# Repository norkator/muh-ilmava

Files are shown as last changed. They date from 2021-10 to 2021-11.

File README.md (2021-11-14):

# MUH Ilmava

MUH Ilmava Arduino temperature and humidity sensing hacks, 
which idea is to learn from gathering temperature and humidity data how this unit works and what can data analysis do.
Another purpose is to see how much this one heat transfer cell can gather heat and how much is dumped to `R4` channel.

See plotting for better image what you can plot with just few DHT22 sensors in each channel.
  
I am currently just waiting due need to gather a lot of data so this repository code could possibly get some more 
"features" based on findings, learning curve and analysis of gathered material.

Ilmava
============
MUH Ilmava is a house ventilation system and this specific unit is very old one from ~1989.

Sensor placing
============
Temperature|humidity sensors labeled as R1, R2, R3, R4 are placed in following way.  
`R1` - Incoming outside air.  
`R2` - Outgoing air to rooms.  
`R3` - Returning air from rooms.  
`R4` - Waste air outside house.

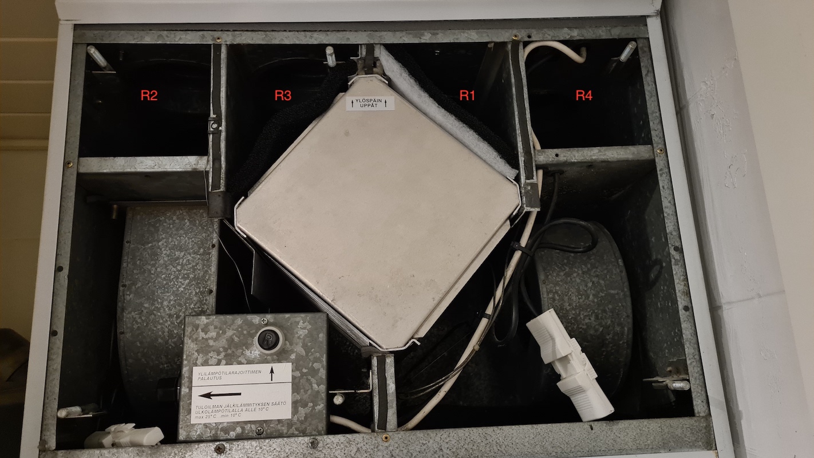
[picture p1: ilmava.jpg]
ilmava_sensor_placing


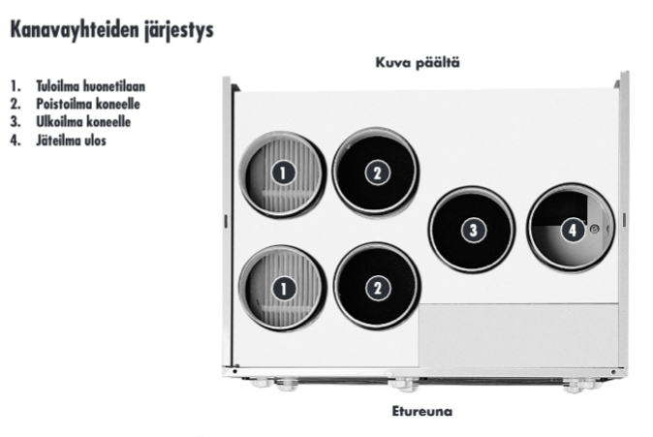
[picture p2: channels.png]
air_channels


Schematic
============
* I used regular 12v power supply to supply main input power. 
* To avoid frying your Arduino regulator, you should use external power regulator like lm2596
to provide 5v out for attached sensors.
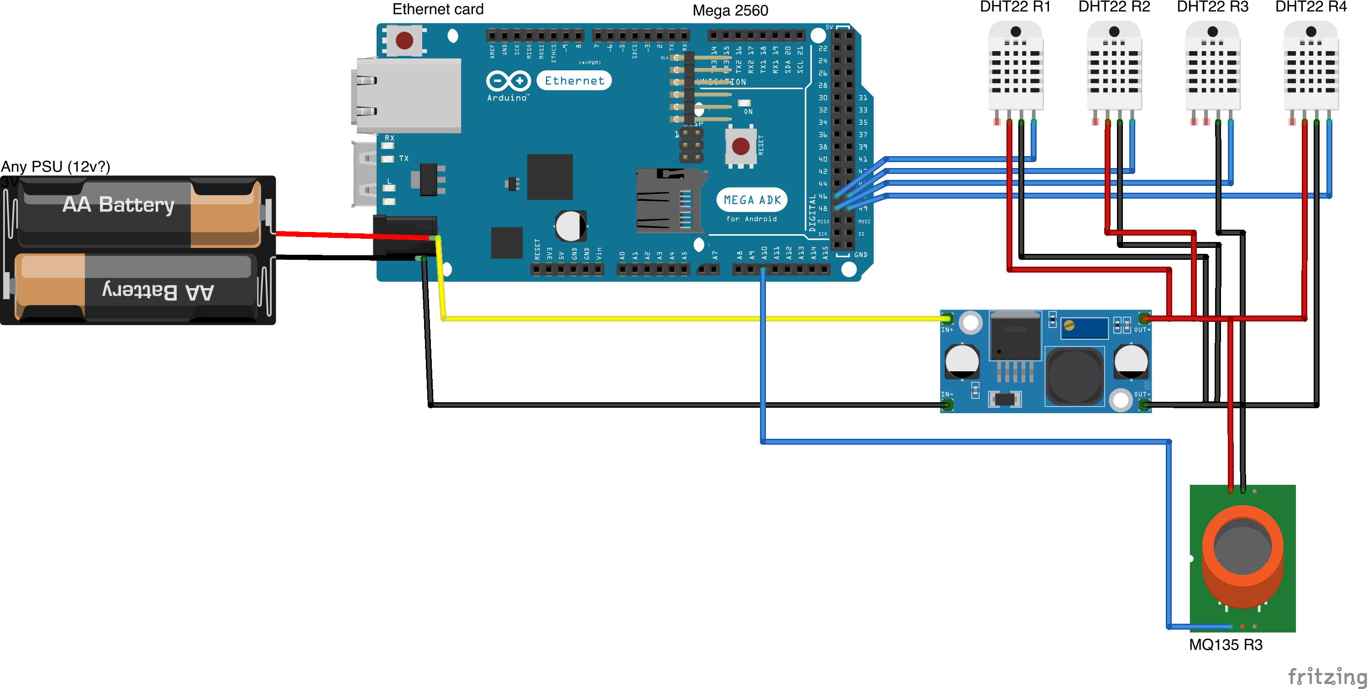
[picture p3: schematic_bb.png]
schematic_bb
 

Backend
============
Is located at `/server` folder. It's a simple express backend which takes data and stores it into PostgreSQL database. 

#### Running backend
Check db schema status
```
yarn migrate:status
```
Migrate to latest schema if needed
```
yarn migrate
```
Run backend. You should run it with something else like `PM2` process manager.
```
node ilmava.js
```

Plotting
============
For plotting data I used `Superset`. I run it locally with Docker as their documentation instructs.
Get started with Superset [here](https://superset.apache.org/).

Why Superset?
* It doesn't no longer make sense to create custom plotting front end since Superset just gives you 
so many possibilities.

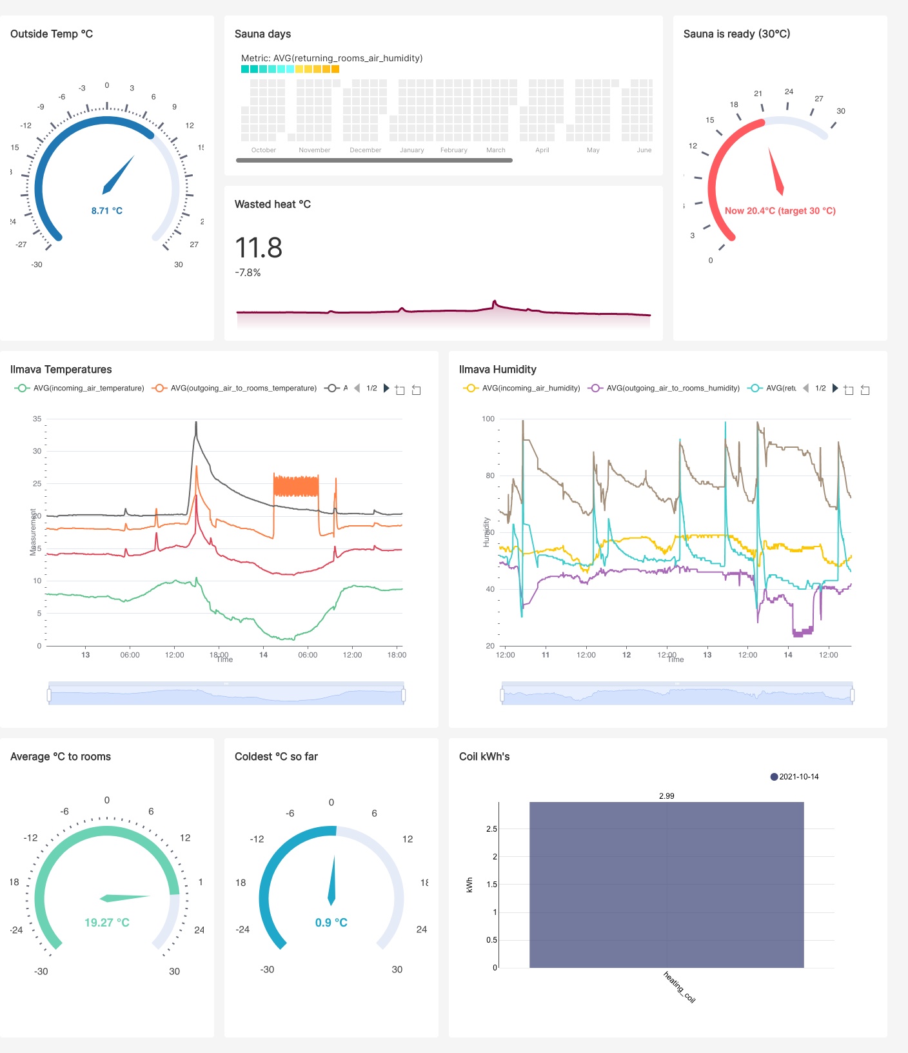
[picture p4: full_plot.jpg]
plotting
 

Queries
============

Need
----
is to find out how much heating coil has used kWh's of energy.  
`500` = coil watt rating.
```postgresql
select
    started::date as date,
    500 * (duration_minutes / 60) / 1000 as used_kwh
from (
         select min("createdAt")                       as started,
                max("createdAt")                       as ended,
                EXTRACT(EPOCH FROM (max("createdAt") - min("createdAt"))::INTERVAL) /
                60                                     as "duration_minutes",
                avg(outgoing_air_to_rooms_temperature) as "avg_temp"
         from measurements
         where outgoing_air_to_rooms_temperature > 21
           and outgoing_air_to_rooms_humidity < 27
         group by "createdAt"::date
     ) as m
```

Coil is not on the whole time so maybe right value is about 70% of it:

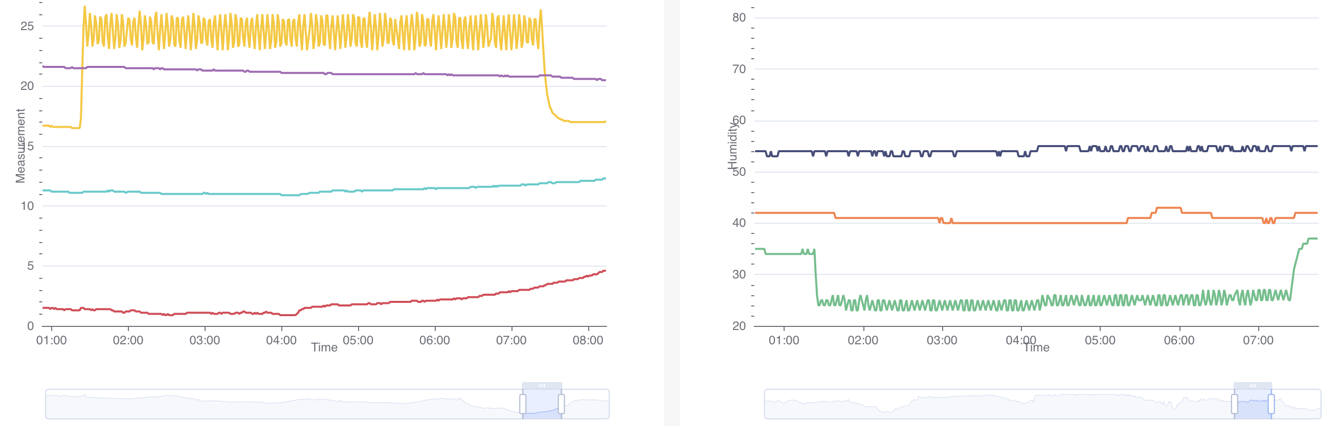
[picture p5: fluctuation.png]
fluctuation


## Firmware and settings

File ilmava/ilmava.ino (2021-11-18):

/**
 * MUH Ilmava Temperature measuring and sender device
 * Arduino: Mega2560
 * Temperature sensors: 4 x DHT22
 * + Ethernet Card (NOTE: 50, 51, 52, 53 are somehow used by wiznet)
 *  
 *  Oled screen support
 *  To enable following screen support you need to install libs: "Adafruit BusIO", "Adafruit-GFX-Library" and "Adafruit_SSD1306"
 *  Display pins:
 *     SDA -> A4 (i2c)
 *     SCL -> A5 (i2c)
 *     GND -> Ground
 *     VDD -> 5v (Screen pin labeled as VCC or VDD)
 *
 */
// --------------------------------------------------------------------------------
// ## Libraries ##
#include <ArduinoJson.h>
#include <SPI.h>
#include <Dhcp.h>
#include <Dns.h>
#include <Ethernet.h>
#include <EthernetClient.h>
#include <EthernetServer.h>
#include <EthernetUdp.h>
#include <ArduinoJson.h>
#include <dht.h>
#include <TaskScheduler.h>
#include <MQ135.h>

// --------------------------------------------------------------------------------
// ## Pins config ##
#define DHT22_1_PIN 46
#define DHT22_2_PIN 47
#define DHT22_3_PIN 48
#define DHT22_4_PIN 49
// const int MQ135_1_PIN = A8;
const int MQ135_2_PIN = A9;
const int MQ135_3_PIN = A10;
// const int MQ135_4_PIN = A11;

// --------------------------------------------------------------------------------
// ## Variables ##
dht DHT;
MQ135 mq2 = MQ135(MQ135_2_PIN, 80.00);
MQ135 mq3 = MQ135(MQ135_3_PIN, 56.39);

double incomingAirTemp = 0.0;
int incomingAirHumidity = 0;
double incomingAirDioxide = 0.0;
double incomingAirMonoxide = 0.0;

double outgoingAirToRoomsTemp = 0.0;
int outgoingAirToRoomsHumidity = 0;
double outgoingAirToRoomsDioxide = 0.0;
double outgoingAirToRoomsMonoxide = 0.0;

double returningRoomsAirTemp = 0.0;
int returningRoomsAirHumidity = 0;
double returningRoomsAirDioxide = 0.0;
double returningRoomsAirMonoxide = 0.0;

double wasteAirOutTemp = 0.0;
int wasteAirOutHumidity = 0;
double wasteAirOutDioxide = 0.0;
double wasteAirOutMonoxide = 0.0;

long timePreviousMeassure = 0;

// --------------------------------------------------------------------------------
// ## "Calibration" ##
static double INCOMING_AIR_T_CORRECTION = 1.2;
static double OUTGOING_AIR_TO_ROOMS_T_CORRECTION = 0.9;
static double RETURNING_ROOMS_AIR_T_CORRECTION = -0.6;
static double WASTE_AIR_OUT_T_CORRECTION = 0.0;

// --------------------------------------------------------------------------------
// ## Ethernet config ##
EthernetClient client;
byte mac[] = { 0x2E, 0xA8, 0xA9, 0xB5, 0xDA, 0xF6 };
const char* server  = "192.168.2.35"; // Where stuff is sent at
const char* api     = "/device/v1/measurements";
const int port      = 8080;
const unsigned long HTTP_TIMEOUT = 10000;
const size_t MAX_CONTENT_SIZE = 1024; // Must be incremented if http response comes out as null

// --------------------------------------------------------------------------------
// ## Task scheduler config ##
Scheduler runner;
void dhtRead();
void dioxideRead();
void monoxideRead();
void httpPostRequest();
Task t1(11 * 1000, TASK_FOREVER, &dhtRead);
Task t2(11 * 1000, TASK_FOREVER, &dioxideRead);
Task t3(11 * 1000, TASK_FOREVER, &monoxideRead);
Task t4(30 * 1000, TASK_FOREVER, &httpPostRequest);    int httpSkip = 0; // Skip some

// --------------------------------------------------------------------------------

// SETUP
void setup() {
  Serial.begin(9600);

  // init ethernet
  if (!Ethernet.begin(mac)) { // DHCP
    Serial.println("Ethernet configure failed!");
  } else {
    Serial.println("Ethernet init ok.");
    Serial.println(Ethernet.localIP());
  }

  // check rzeros for mq sensors 
  float rzero_2 = mq2.getRZero();
  float rzero_3 = mq3.getRZero();
  Serial.println("MQ135 Rzeros");
  Serial.println(rzero_2);
  Serial.println(rzero_3);

  // init task scheduler
  runner.init();
  runner.addTask(t1); // dht
  runner.addTask(t2); // dioxide
  runner.addTask(t3); // monoxide
  runner.addTask(t4); // http call
  t1.enable();
  t2.enable();
  t3.enable();
  t4.enable();

  delay(5 * 1000);
}

// --------------------------------------------------------------------------------

// LOOP
void loop() {
  runner.execute(); // Runner is responsible for all tasks
}

// --------------------------------------------------------------------------------------------------------------------------
// -------------------------------------A L L - S E N S O R - R E A D I N G - T A S K S -------------------------------------
// --------------------------------------------------------------------------------------------------------------------------

// Read DHT temperature and humidity
void dhtRead() {  
  int chk = DHT.read22(DHT22_1_PIN);  
  incomingAirTemp = DHT.temperature + INCOMING_AIR_T_CORRECTION;
  incomingAirHumidity = DHT.humidity;
  Serial.print("Incoming Air temp: ");
  Serial.print(incomingAirTemp);
  Serial.println("°C");
  Serial.print("Incoming Air humidity: ");
  Serial.print(incomingAirHumidity);
  Serial.println("rH");

  chk = DHT.read22(DHT22_2_PIN);  
  outgoingAirToRoomsTemp = DHT.temperature + OUTGOING_AIR_TO_ROOMS_T_CORRECTION;
  outgoingAirToRoomsHumidity = DHT.humidity;
  Serial.print("Outgoing Air To Rooms temp: ");
  Serial.print(outgoingAirToRoomsTemp);
  Serial.println("°C");
  Serial.print("Outgoing Air To Rooms humidity: ");
  Serial.print(outgoingAirToRoomsHumidity);
  Serial.println("rH");

  chk = DHT.read22(DHT22_3_PIN);  
  returningRoomsAirTemp = DHT.temperature + RETURNING_ROOMS_AIR_T_CORRECTION;
  returningRoomsAirHumidity = DHT.humidity;
  Serial.print("Returning Rooms Air temp: ");
  Serial.print(returningRoomsAirTemp);
  Serial.println("°C");
  Serial.print("Returning Rooms Air humidity: ");
  Serial.print(returningRoomsAirHumidity);
  Serial.println("rH");

  chk = DHT.read22(DHT22_4_PIN);  
  wasteAirOutTemp = DHT.temperature + WASTE_AIR_OUT_T_CORRECTION;
  wasteAirOutHumidity = DHT.humidity;
  Serial.print("Waste Air Out temp: ");
  Serial.print(wasteAirOutTemp);
  Serial.println("°C");
  Serial.print("Waste Air Out humidity: ");
  Serial.print(wasteAirOutHumidity);
  Serial.println("rH");

  Serial.println("------------------------------------");
}

// Read carbon dioxide sensors (MQ-135)
void dioxideRead() {
  // outgoingAirToRoomsDioxide = analogRead(MQ135_2_PIN);
  outgoingAirToRoomsDioxide = mq2.getCorrectedPPM(outgoingAirToRoomsTemp, returningRoomsAirHumidity);
  Serial.print("Outgoing Air To Rooms carbon dioxide: ");
  Serial.print(outgoingAirToRoomsDioxide);
  Serial.println(" PPM");
  
  // returningRoomsAirDioxide = analogRead(MQ135_3_PIN);
  returningRoomsAirDioxide = mq3.getCorrectedPPM(returningRoomsAirTemp, returningRoomsAirHumidity);
  Serial.print("Returning Rooms Air carbon dioxide: ");
  Serial.print(returningRoomsAirDioxide);
  Serial.println(" PPM");

  Serial.println("------------------------------------");
}

// Read carbon monoxide sensors (MQ-9)
void monoxideRead() {
  // currently don't have any
}


// --------------------------------------------------------------------------------------------------------------------------
// ----------------------------------------- H T T P - A P I - C A L L - T A S K --------------------------------------------
// --------------------------------------------------------------------------------------------------------------------------

// Http post operation
void httpPostRequest() {
    if (httpSkip == 0) {
      Serial.print("Http callback");
      if (connect(server)) {
        Serial.print(server); Serial.print(":"); Serial.print(port); Serial.println(api);
        if (sendRequest(server, api) && skipResponseHeaders()) {
          char response[MAX_CONTENT_SIZE];
          readReponseContent(response, sizeof(response));
          parseResponseData(response);
        }
        disconnect();
      }
    }
    httpSkip = httpSkip +1;
    if (httpSkip == 2) {
      httpSkip = 0;
    };
}

// Open connection to the HTTP server
bool connect(const char* hostName) {
  Serial.println("");
  Serial.print("Connecting to: ");
  Serial.print(hostName); Serial.print(":"); Serial.print(port);
  Serial.println("");
  bool ok = client.connect(hostName, port);
  Serial.println(ok ? "Connected" : "Connection Failed!");
  Serial.println(client.remoteIP());
  return ok;
}

// Send the HTTP POST request to the server, same time GET needed response data
bool sendRequest(const char* host, const char* api) {

  // Construct json parameter object
  StaticJsonBuffer<1200> jsonBuffer; // This seems not to affect anywhere
  StaticJsonBuffer<500> jsonBuffer2; // Increment more based on Object count
  JsonObject& root = jsonBuffer.createObject();
  // root["firmwareBuild"] = firmware_build;
  JsonArray& data = root.createNestedArray("data");

  JsonObject& incomingAirObj = jsonBuffer2.createObject();
  incomingAirObj["name"] = "incoming_air";
  incomingAirObj["temp"] = incomingAirTemp;
  incomingAirObj["hum"] = incomingAirHumidity;
  // incomingAirObj["dioxide"] = incomingAirDioxide;
  // incomingAirObj["monoxide"] = incomingAirMonoxide;

  JsonObject& outgoingAirToRoomsObj = jsonBuffer2.createObject();
  outgoingAirToRoomsObj["name"] = "outgoing_air_to_rooms";
  outgoingAirToRoomsObj["temp"] = outgoingAirToRoomsTemp;
  outgoingAirToRoomsObj["hum"] = outgoingAirToRoomsHumidity;
  outgoingAirToRoomsObj["dioxide"] = outgoingAirToRoomsDioxide;
  // outgoingAirToRoomsObj["monoxide"] = outgoingAirToRoomsMonoxide;

  JsonObject& returningRoomsAirObj = jsonBuffer2.createObject();
  returningRoomsAirObj["name"] = "returning_rooms_air";
  returningRoomsAirObj["temp"] = returningRoomsAirTemp;
  returningRoomsAirObj["hum"] = returningRoomsAirHumidity;
  returningRoomsAirObj["dioxide"] = returningRoomsAirDioxide;
  // returningRoomsAirObj["monoxide"] = returningRoomsAirMonoxide;
  

  JsonObject& wasteAirOutObj = jsonBuffer2.createObject();
  wasteAirOutObj["name"] = "waste_air_out";
  wasteAirOutObj["temp"] = wasteAirOutTemp;
  wasteAirOutObj["hum"] = wasteAirOutHumidity;
  wasteAirOutObj["dioxide"] = wasteAirOutDioxide;
  // wasteAirOutObj["monoxide"] = wasteAirOutMonoxide;

  // Append to data array
  data.add(incomingAirObj);
  data.add(outgoingAirToRoomsObj);
  data.add(returningRoomsAirObj);
  data.add(wasteAirOutObj);

  String postData = "";
  root.printTo(postData);
  Serial.println(postData);

  // Http post
  Serial.print("POST ");
  Serial.println(api);
  client.print("POST ");
  client.print(api);
  client.println(" HTTP/1.1");
  client.print("Host: ");
  client.println(server);
  //client.println("Content-Type: application/x-www-form-urlencoded");
  client.println("Content-Type: application/json");
  client.println("User-Agent: Arduino/1.0");
  client.println("Connection: close");
  client.print("Content-Length: ");
  client.println(postData.length());
  client.println();
  client.print(postData);
  client.println();

  return true;
}

// --------------------------------------------------------------------------------

// Skip HTTP headers so that we are at the beginning of the response's body
bool skipResponseHeaders() {
  // HTTP headers end with an empty line
  char endOfHeaders[] = "\r\n\r\n";
  client.setTimeout(HTTP_TIMEOUT);
  bool ok = client.find(endOfHeaders);
  if (!ok) {
    Serial.println("No response or invalid response!");
  }
  return ok;
}

// --------------------------------------------------------------------------------

// Read the body of the response from the HTTP server
void readReponseContent(char* content, size_t maxSize) {
  size_t length = client.readBytes(content, maxSize);
  content[length] = 0;
}

// --------------------------------------------------------------------------------

// Parse response data (commands) and apply them
void parseResponseData(char* content) {
  StaticJsonBuffer<MAX_CONTENT_SIZE> jsonBuffer; // Increment MAX_CONTENT_SIZE constant variable if repsonse is null
  JsonObject& root = jsonBuffer.parseObject(content);

  Serial.println("---------- HTTP RESPONSE ----------");
  String responseData = "";
  Serial.println(responseData);
  Serial.println("-----------------------------------");

  if (!root.success()) {
    Serial.println("JSON parsing failed!");
    return;
  }

}

// --------------------------------------------------------------------------------

// Close the connection with the HTTP server
void disconnect() {
  Serial.println("Disconnect");
  client.stop();
}

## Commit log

2021-10-04 Code to read temps
    Some skeleton celsius converter which most likely does not work
    [ilmava.ino]
2021-10-04 Add sensor placing plan
2021-10-04 Fixed code to cover all requirements
    [ilmava.ino]
2021-10-09 Take up previous millis
2021-10-10 Refactored Arduino side code
2021-10-10 Final sensor placement and renaming
2021-10-10 now inserts data into table
2021-10-10 Update sensor placing photo
2021-10-10 Update schematic
    [schematic.fzz]
2021-10-12 Add some calibration so that all sensors would have same temp measurement in same room
2021-10-14 Heating coil related investigation and query
2021-10-19 exclude current day to get whole day measurement involved
2021-11-14 Carbon dioxide sensors (#1)
    * add sequelize cli for running migrations
    * stock sequelize init files
    * get credentials from env file instead
    * update readme, add skeleton migration file
    * add new table model fields
    * add migration to add new fields
    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
    [schematic.fzz]
2021-11-16 activate another carbon dioxide sensor
2021-11-17 Tweaking carbon monoxide sensing (#3)
    * Testing MQ135 library for corrected values
    * add MQ135 library zip
    * Changing to another version of MQ135 library
    * Update ilmava.ino
    [ilmava.ino]
2021-11-18 recalibration of mq135 sensors
